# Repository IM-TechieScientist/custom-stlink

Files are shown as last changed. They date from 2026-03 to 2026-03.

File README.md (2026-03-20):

# Custom-STlink
A custom STLink compatible debugger using STM32F103 designed using KiCAD
Meant to work with stlink firmware dump or even better Black Magic Probe.

Versions:
V1- Includes USB Type C and SWD Debug points. 



Planned:
V2 - Standalone Flasher/Field Debugger with onboard SDMMC and a display to select which program to flash.

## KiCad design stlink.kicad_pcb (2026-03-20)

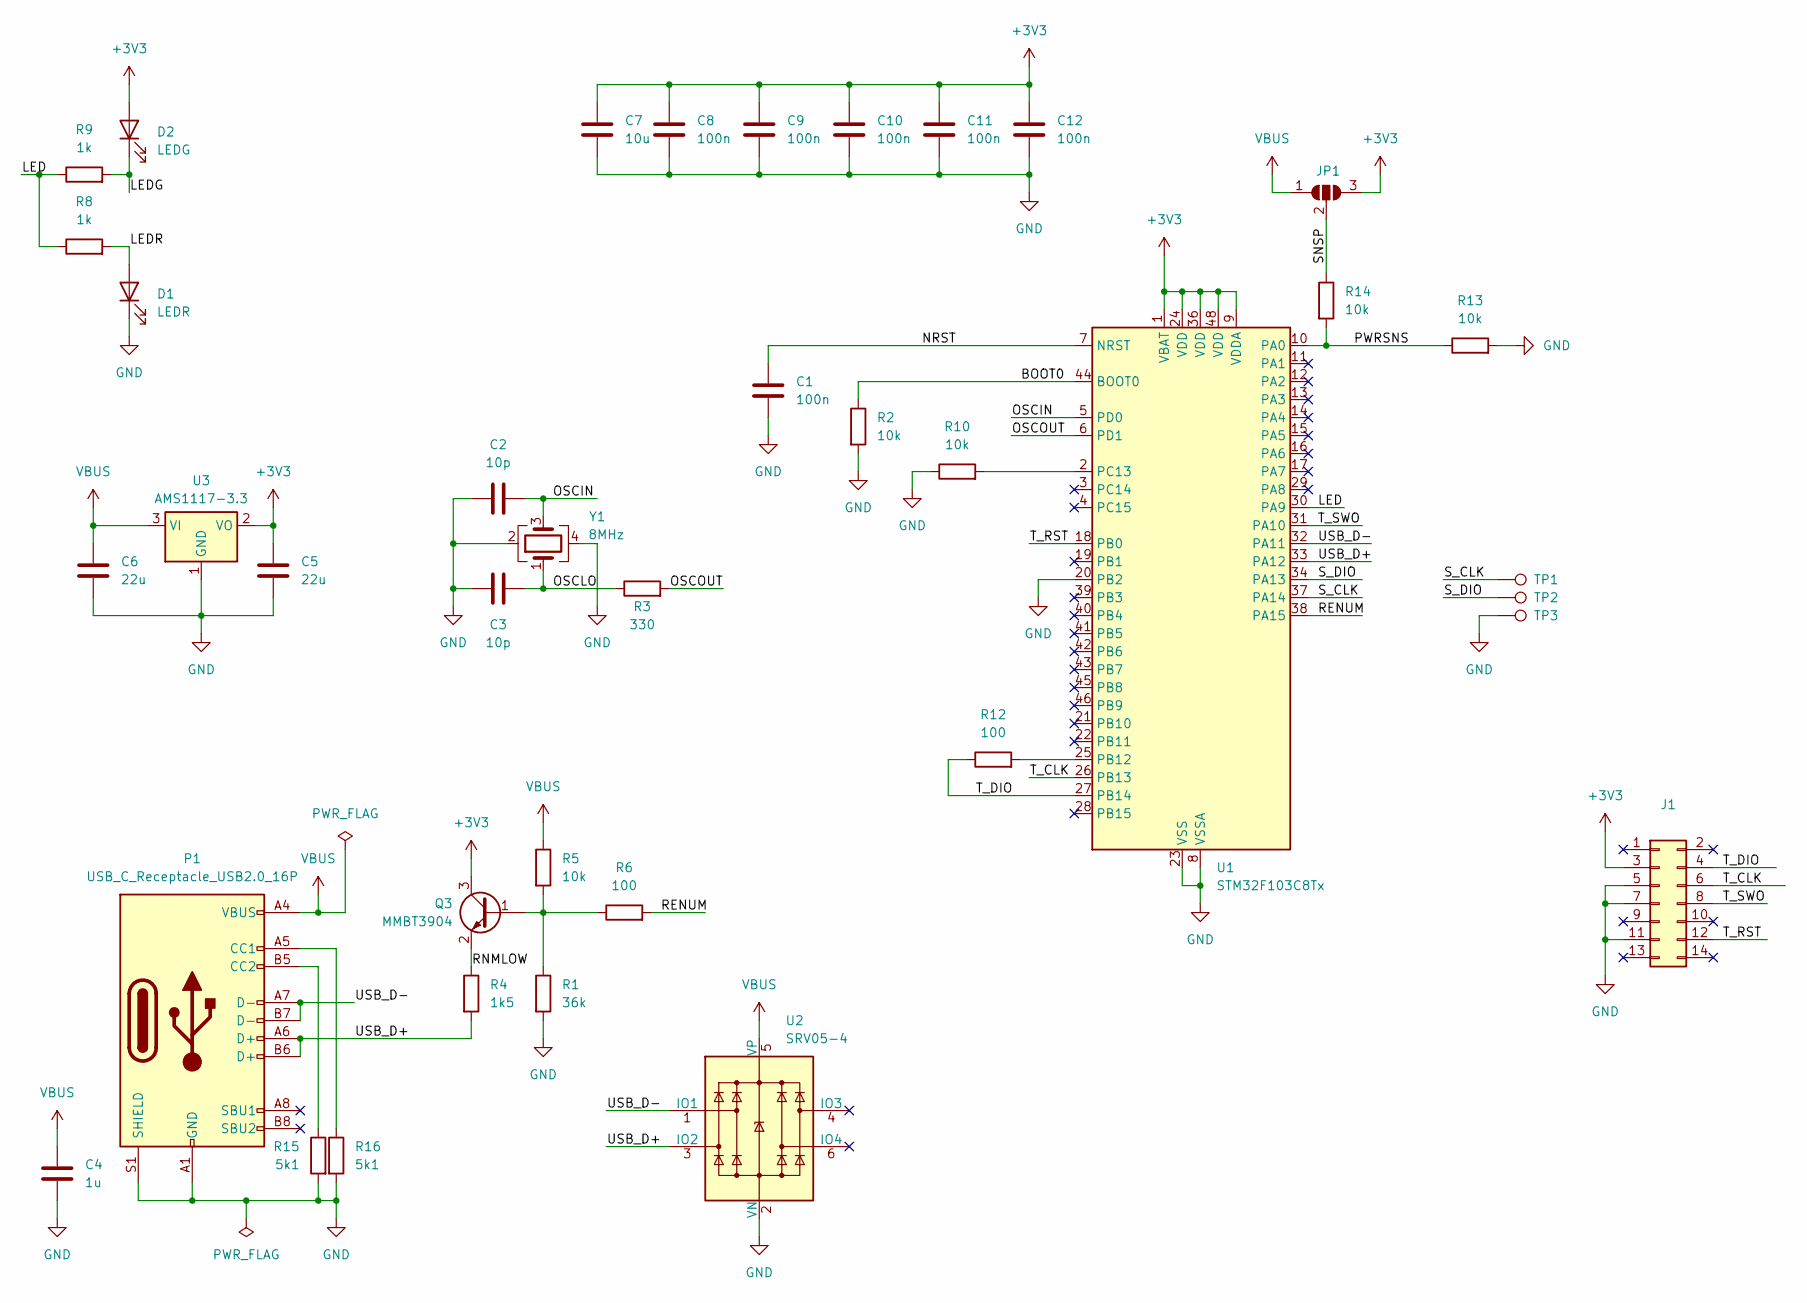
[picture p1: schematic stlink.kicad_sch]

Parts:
C1, C8, C9, C10, C11, C12: 100n; C_0402_1005Metric
C2, C3: 10p; C_0402_1005Metric
C4: 1u; C_0402_1005Metric
C5: 22u; C_0603_1608Metric
C6: 22u; C_0805_2012Metric
C7: 10u; C_0402_1005Metric
D1: LEDR; LED_0603_1608Metric; LCSC C2286
D2: LEDG; LED_0603_1608Metric; LCSC C2986059
J1: Conn_02x07_Odd_Even; PinHeader_2x07_P1.27mm_Vertical; LCSC C2881789
JP1: SolderJumper_3_Open; SolderJumper-3_P1.3mm_Open_RoundedPad1.0x1.5mm
P1: USB_C_Receptacle_USB2.0_16P; USB_C_Receptacle_GCT_USB4105-xx-A_16P_TopMnt_Horizontal; MPN C165948
Q3: MMBT3904; SOT-23
R1: 36k; R_0402_1005Metric
R2, R5, R10, R13, R14: 10k; R_0402_1005Metric
R3: 330; R_0402_1005Metric
R4: 1k5; R_0402_1005Metric
R6, R12: 100; R_0402_1005Metric
R8, R9: 1k; R_0402_1005Metric
R15, R16: 5k1; R_0402_1005Metric; LCSC C25905
TP1, TP2, TP3: TestPoint; TestPoint_Pad_D1.0mm
U1: STM32F103C8Tx; LQFP-48_7x7mm_P0.5mm; LCSC C8734
U2: SRV05-4; SOT-23-6; LCSC C7420376
U3: AMS1117-3.3; SOT-223-3_TabPin2
Y1: 8MHz; Crystal_SMD_3225-4Pin_3.2x2.5mm; LCSC C400090

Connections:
+3V3: C5.1, C7.1, C8.1, C9.1, C10.1, C11.1, C12.1, D2.2 (A), J1.3, JP1.3 (B), Q3.3 (C), U1.1 (VBAT), U1.9 (VDDA), U1.24 (VDD), U1.36 (VDD), U1.48 (VDD), U3.2 (VO)
/BOOT0: R2.1, U1.44 (BOOT0)
/LED: R8.1, R9.1, U1.30 (PA9)
/LEDG: D2.1 (K), R9.2
/LEDR: D1.2 (A), R8.2
/NRST: C1.1, U1.7 (NRST)
/OSCIN: C2.2, U1.5 (PD0), Y1.3
/OSCLO: C3.2, R3.1, Y1.1
/OSCOUT: R3.2, U1.6 (PD1)
/PWRSNS: R13.1, R14.2, U1.10 (PA0)
/RENUM: R6.2, U1.38 (PA15)
/RNMLOW: Q3.2 (E), R4.1
/SNSP: JP1.2 (C), R14.1
/S_CLK: TP1.1, U1.37 (PA14)
/S_DIO: TP2.1, U1.34 (PA13)
/T_CLK: J1.6, U1.26 (PB13)
/T_DIO: J1.4, R12.1, U1.27 (PB14)
/T_RST: J1.12, U1.18 (PB0)
/T_SWO: J1.8, U1.31 (PA10)
/USB_D+: P1.A6 (D+), P1.B6 (D+), R4.2, U1.33 (PA12), U2.3 (IO2)
/USB_D-: P1.A7 (D-), P1.B7 (D-), U1.32 (PA11), U2.1 (IO1)
GND: C1.2, C2.1, C3.1, C4.2, C5.2, C6.2, C7.2, C8.2, C9.2, C10.2, C11.2, C12.2, D1.1 (K), J1.5, J1.7, J1.11, P1.A1 (GND), P1.A12 (GND), P1.B1 (GND), P1.B12 (GND), P1.S1 (SHIELD), R1.2, R2.2, R10.1, R13.2, R15.2, R16.2, TP3.1, U1.8 (VSSA), U1.20 (PB2), U1.23 (VSS), U1.35 (VSS), U1.47 (VSS), U2.2 (VN), U3.1 (GND), Y1.2, Y1.4
unnamed: P1.A5 (CC1), R16.1
unnamed: P1.B5 (CC2), R15.1
unnamed: Q3.1 (B), R1.1, R5.2, R6.1
unnamed: R12.2, U1.25 (PB12)
unnamed: R10.2, U1.2 (PC13)
VBUS: C4.1, C6.1, JP1.1 (A), P1.A4 (VBUS), P1.A9 (VBUS), P1.B4 (VBUS), P1.B9 (VBUS), R5.1, U2.5 (VP), U3.3 (VI)

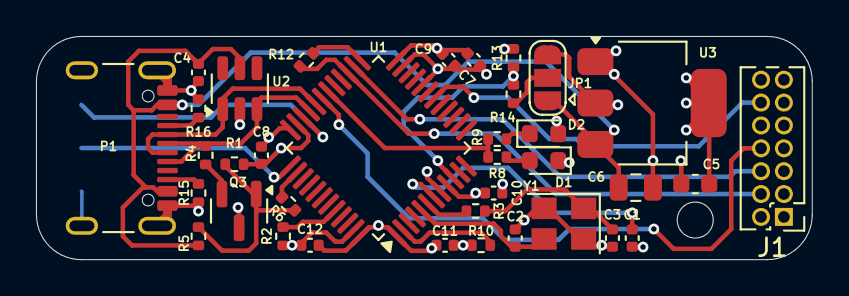
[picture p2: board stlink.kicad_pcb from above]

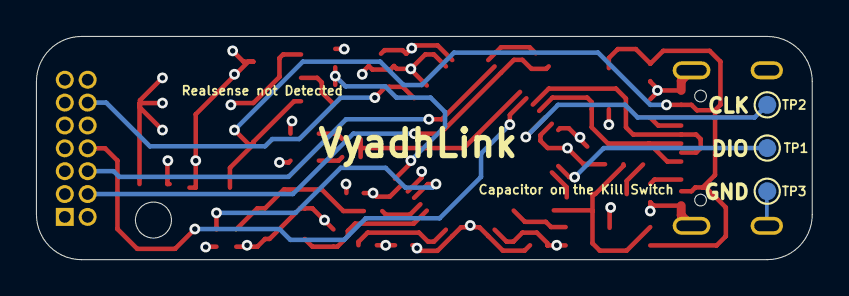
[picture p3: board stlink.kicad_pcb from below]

Board: 4 copper layers, 43.1 x 12.4 mm, 39 parts (3 on the bottom side), 28 nets.
